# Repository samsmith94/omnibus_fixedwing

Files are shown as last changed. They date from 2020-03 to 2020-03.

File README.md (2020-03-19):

# Supplementary board for Omnibus F4 V3.

With this board, you can relocate your Omnibus Flight Controller to another model, since soldering is not required at all.

It is very convenient to use with the on-board
- GY-NEO8MV2 pin header
- 3-pin JST connector for FPV camera
- 3-pin JST connector for FPV transmitter
- 6-pin JST connector for Racerstar Shot30AESC
- 3-pin connector for WS2812B LED strip
- piezo buzzer.

Additionally there is an RFM95 LoRa modul + Atmega 328P + SMA connector for experimental LoRa-RC.

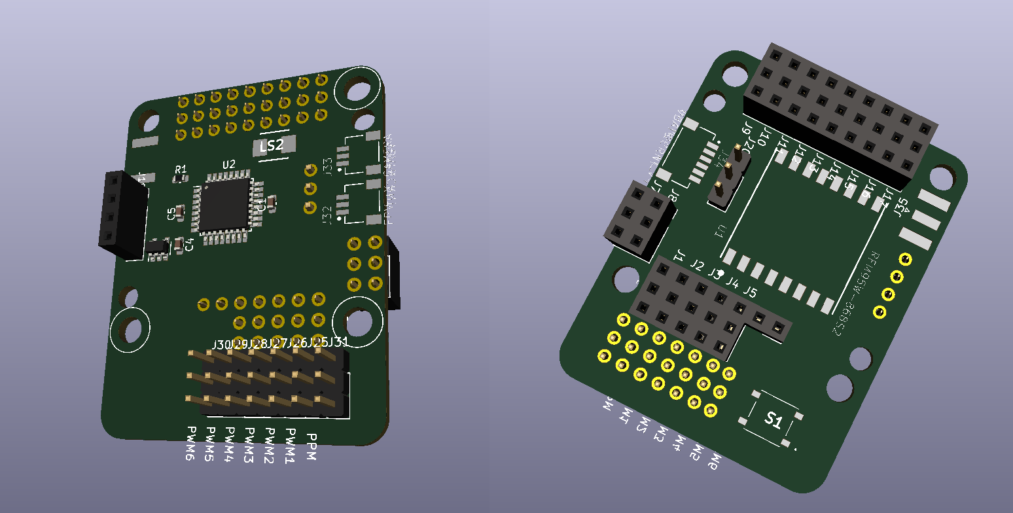
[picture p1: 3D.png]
3D model


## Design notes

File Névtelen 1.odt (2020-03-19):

1 mm pitch SMD female PCB aljzat + 10 cm wire

https://www.amazon.com/JST-SH-Female-Connector-Straight-Header/dp/B07KYHKSLN

Rendes boltból (farnell)

https://hu.farnell.com/w/c/connectors/wire-to-board-connectors?pitch-spacing=1mm&no-of-contacts=3contacts

konkrétan ez a legjobb

https://hu.farnell.com/jst-japan-solderless-terminals/sm03b-srss-tb-lf-sn/header-r-a-3way/dp/1679118

hozzá snapeda footprint&symbol

https://www.snapeda.com/parts/SM03B-SRSS-TB(LF)(SN)/JST/view-part/

omnibus dokumentáció

https://newtn.net/flori-schmid/2017/08/14/omnibus-f4-v3-documentation/

https://github.com/betaflight/betaflight/wiki/Board---OMNIBUSF4

https://www.youtube.com/watch?v=z3gCFm83cVw

lorarc

https://www.youtube.com/watch?v=bZgweGUDXOE

https://github.com/winiak/LoRaRC

atmega328 a lorahoz

https://www.hestore.hu/prod_10032542.html

betaflght fixed wing setup

https://github.com/betaflight/betaflight/wiki/Setup-for-a-Fixed-Wing-Aircraft

olcsó buzzer

https://hu.mouser.com/ProductDetail/TDK/PS1240P02BT?qs=sGAEpiMZZMs%252B6Ea5iKw4JnKB8rEmL0Rz

turnigy binb

https://www.youtube.com/watch?v=SnbP73vutww

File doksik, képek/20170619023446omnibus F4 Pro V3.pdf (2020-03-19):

Omnibus F4 Pro V3 Pinout

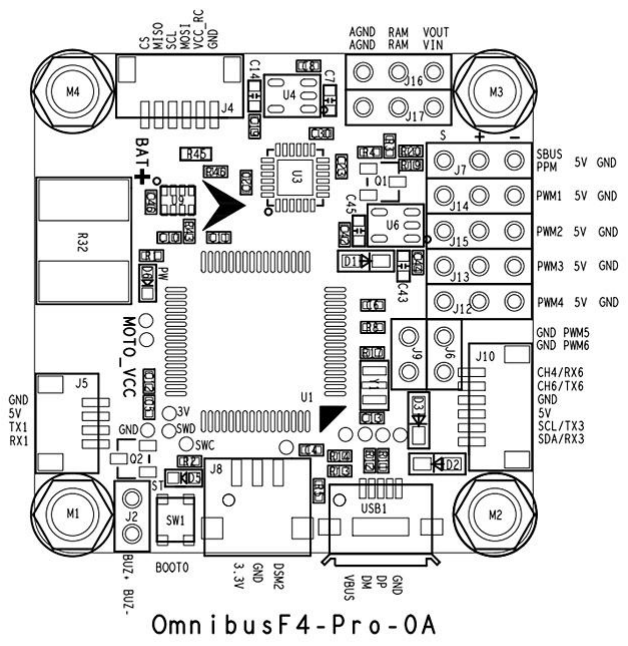
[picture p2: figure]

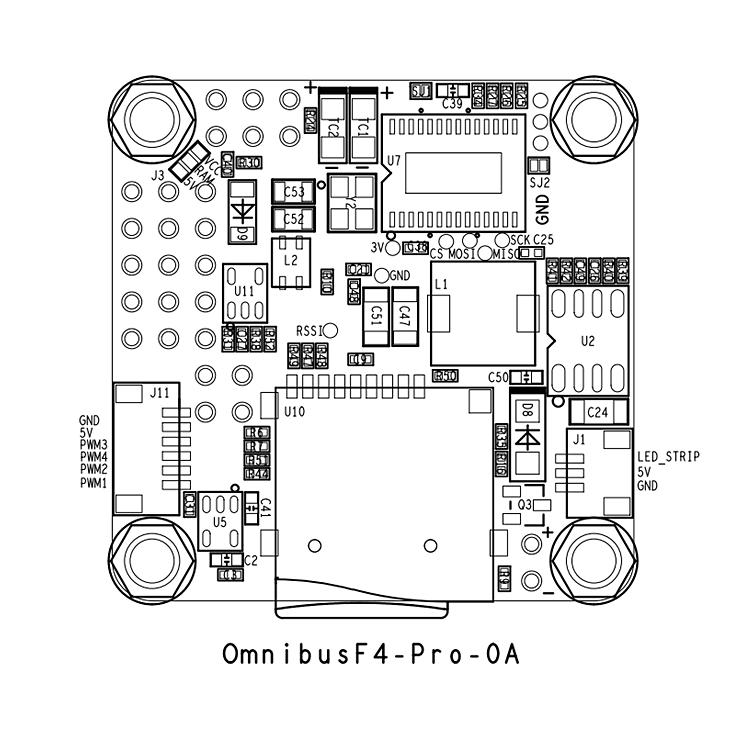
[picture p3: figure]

Wiring Diagram

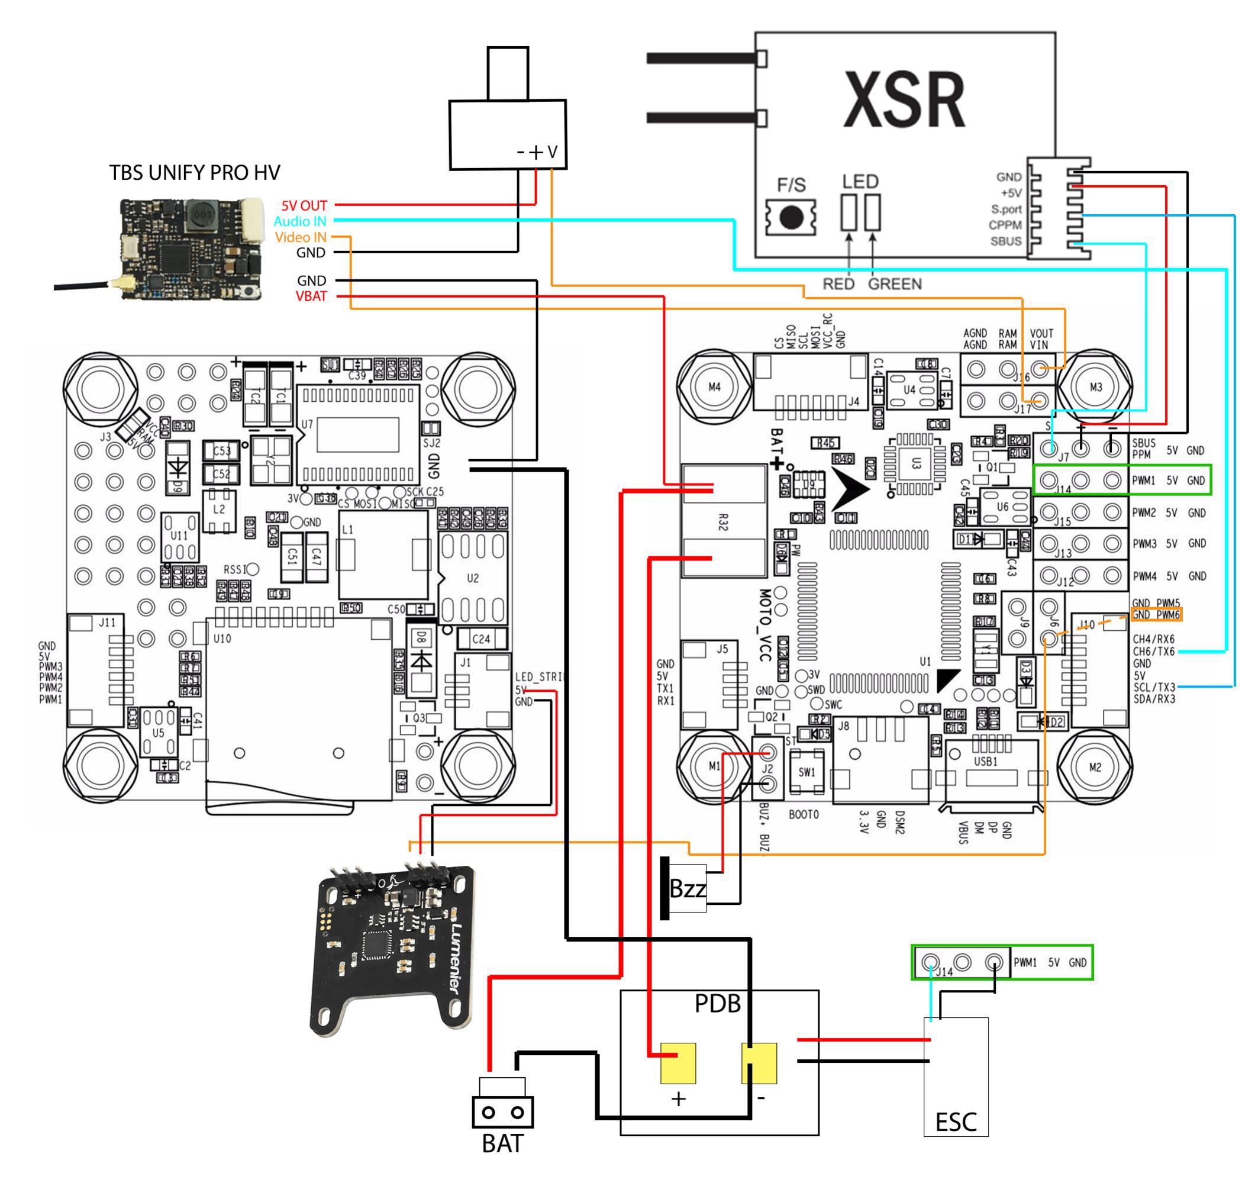
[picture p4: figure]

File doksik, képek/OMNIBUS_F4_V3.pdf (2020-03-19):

1 4 . A U G U S T 2 0 1 7 | V O N | F L O R I

# OMNIBUS F4 V3 – Documentation

Since there is no documentation at all on any of these F4 boards, here is my try:
– STM32F405 LQFP64 (168Mhz, 1M ash, 192kB SRAM)
– MPU6000 6DOF IMU
– BMP280 barometer
– MAX7456 OSD (or fake)
– 5V Switching regulator (MP2359)
– 6pin SM06B-SRSS connector to ESC (ts Racestar RS20A4V2) – DSM2 port for SPEKTRUM satellit
– USB CDC serial, DFU rmware update
– micro SD card slot for Blackbox logging

Latest rmware on Betaight github releases (V3.2.0) Congurator as Chrome App

Specication:
Power Supply MP2359 (1.4MHz switching regulator)
Input Voltage: max 24V (input capacitors may limit voltage to 4S) Output Current: max. 1.2A (1.8A current Limit)

3.3V LDO (100mA?)

Accessable pins

LABEL PIN TIMER DMA LQFP64
PIN

NOTE

RSSI | A0 | | | 14 | Not ADC capable
PWM5 | A1 | 5,2 | 1,4 | 15 | SoftSer 11 RX(/TX)
PWM4 | A2 2,3 | 1,1 | 16 | Motor 4
PWM3 | A3 2,4 | 1,6 | 17 | Motor 3
PWM6 | A8 1,1 | 2,3 | 41 | SoftSer 11 TX(/RX)
UART1 TX | A9 1,2 | 2,2 | 42
UART1 RX | A10 1,3 | ?,? | 43 | DSM2 SPEKSAT
PWM1 | B0 3,3 | 1,7 | 26 | Motor 1
PWM2 | B1 | 3,4 | 1,2 | 27 | Motor 2
Buzzer | B4 | | | 56
LED_STRIP B6 4,1 | 1,0 | 58 | WS2812 LED
PPM | B8 12,3 | n.a | 61 | PPM (if jumpered)
CH2 | B9 | | | 62 | ? wrong in BF github.
UART3 TX B10 2,3(!) | ?,? | 29 | Shared I²C resource
UART3 RX B11 2,4(!) | ?,? | 30 | Shared I²C resource
CRNT | C1 | — | 2,4 | 9 | external current sense ADC
VBAT | C2 — | 2,4 | 10 | internal VBat voltage
| | | | | divider ADC

LABEL PIN TIMER DMA LQFP64 PIN

NOTE

UART6 TX C6 8,1 | 2,2 | 37
UART6 RX C7 8,2 | 2,3 | 38 | SBUS (if jumpered)

Note: Serial ports in CAPITALs are Serial1; Serial3; Serial6, Serial11 (=SoftSer1); Serial12 (=SoftSer2)
In sourcecode and portforwarding use number-1: serial0; serial2; serial5…

Internal

LABEL | PORT TIMER DMA LQFP64
PIN

NOTE

USB_D+ | A12 | 45 | USB data plus
USB_D- | A11 | 44 | USB data minus
SWD | A13 | 46 | SWD_DIO
SWC | A14 | 49 | SWD_CLK
OSC_IN | H0 | 5
OSC_OUT | H1 | 6
SPI1_MISO | A6 | 22 | MPU600 SPI
SPI1_MOSI | A7 | 23
SPI1_CLK | A5 | 21
SPI1_CS_MPU A4 | 20
MPU_INT | C4 | 24

MPU6000
Interrupt output
SPI2_MISO | B14 | 35 | SD card SPI
SPI2_MOSI | B15 | 36

LABEL | PORT TIMER DMA LQFP64
PIN

NOTE

SPI2_CLK | B13 | 34
SPI2_CS_SD | B12 | 33
SD_DETECT | B7 | 59 | SD Card detect switch
SPI3_MISO | C11 | 52 | BARO & OSD SPI
SPI3_MOSI | C12 | 53
SPI3_CLK | C10 | 51
SPI3_CS_Baro B3 | 55
SPI3_CS_OSD A15 | 50
INVERTER | C8 | 39 | Logic Level inverter enable
LED1 | C5 | 57 | onboard LED (blue)
| B2 | 28 | GND
| C3 | 11 | resistor with NRST?
| C13 | 2 | unrouted
| C14 | 3 | unrouted
| C15 | 4 | unrouted

Where to buy:
ebay (DE)
ebay (CN)

The following is pretty much for my own conguration, but might be useful for you as well:

Set throotle check min:
set min_check = 1045

Setup SoftSer 11 for runcam control: resource Motor 5 none
resource Motor 6 none
resource serial_rx 11 A1
resource serial_tx 11 A8

Get Mag working on UART3/I²C2: resource Serial_TX 3 none
resource Serial_RX 3 none
resource i2c_scl 2 b10
resource i2c_sda 2 b11

Dont forget to:
save

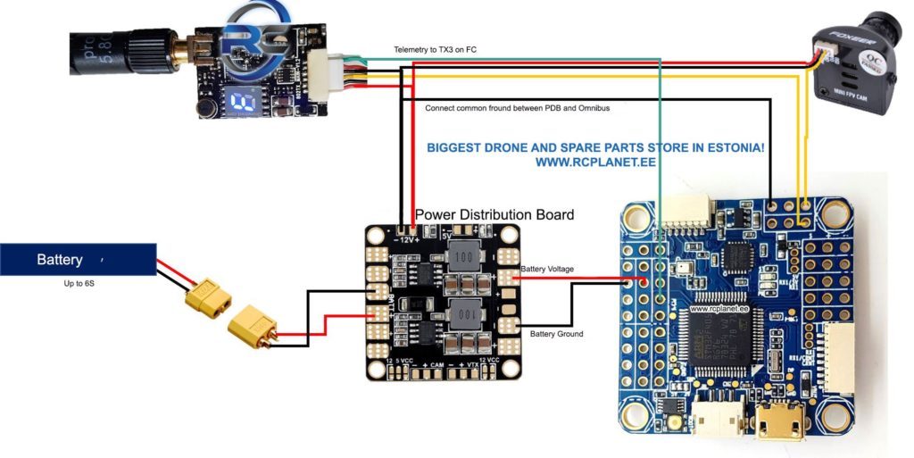
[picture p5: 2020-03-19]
doksik, képek/vbat és kamera.jpg

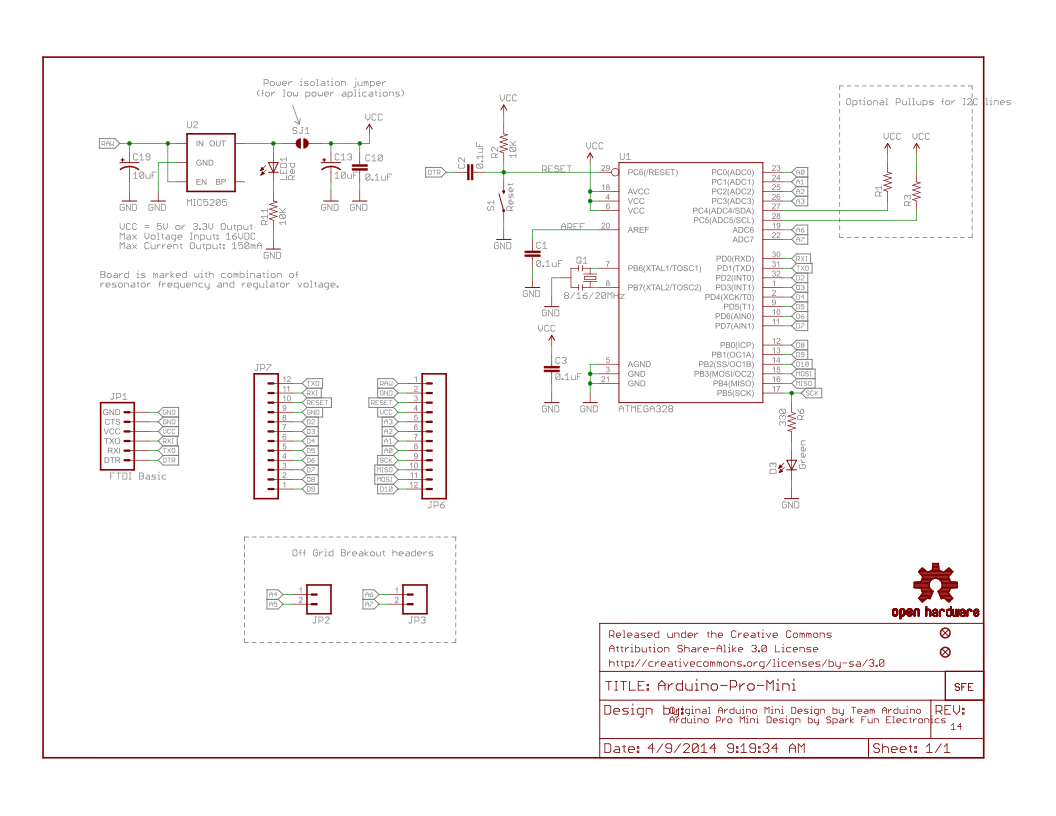
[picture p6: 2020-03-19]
doksik, képek/Arduino-Pro-Mini-v14.gif

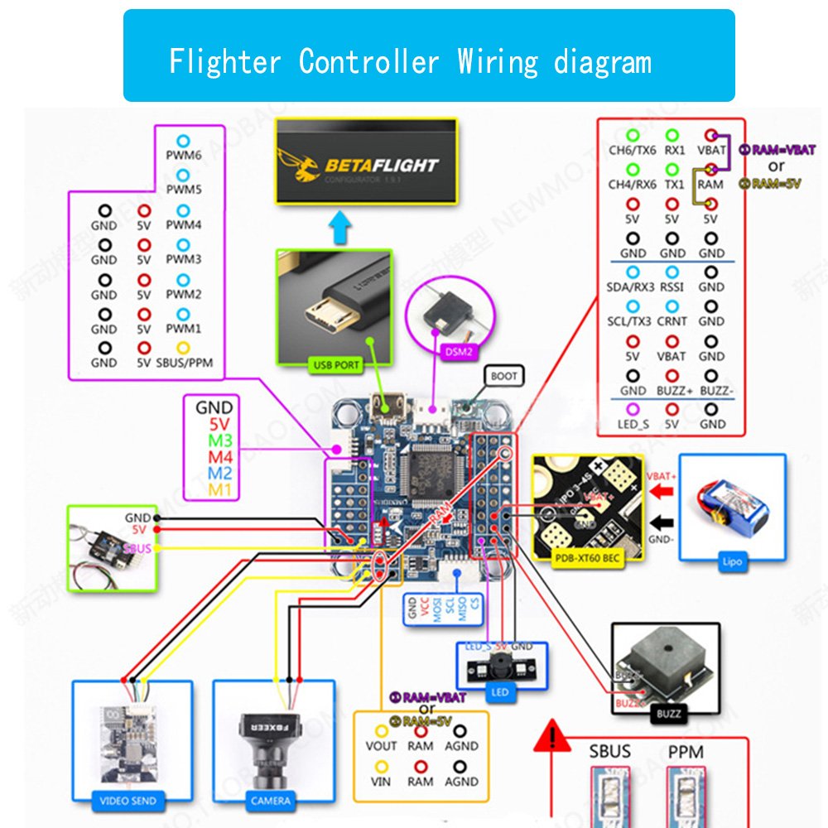
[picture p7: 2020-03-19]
doksik, képek/minden pin.jpg

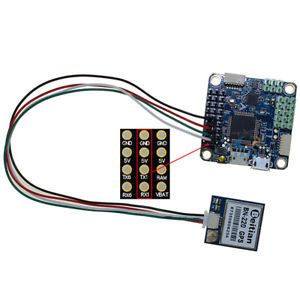
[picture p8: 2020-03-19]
doksik, képek/gps.jpg

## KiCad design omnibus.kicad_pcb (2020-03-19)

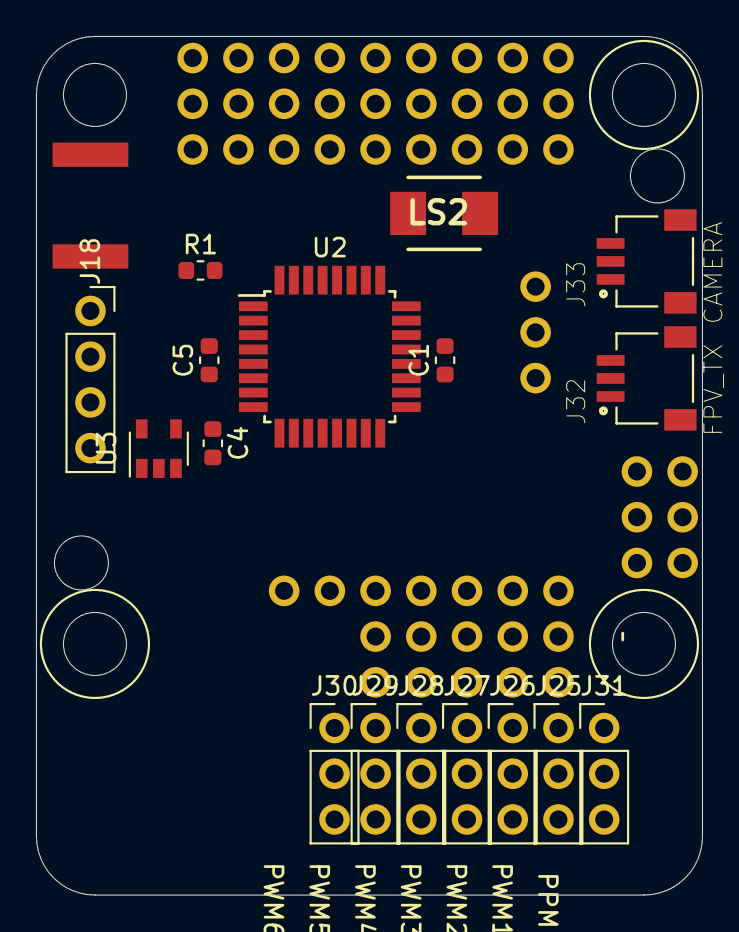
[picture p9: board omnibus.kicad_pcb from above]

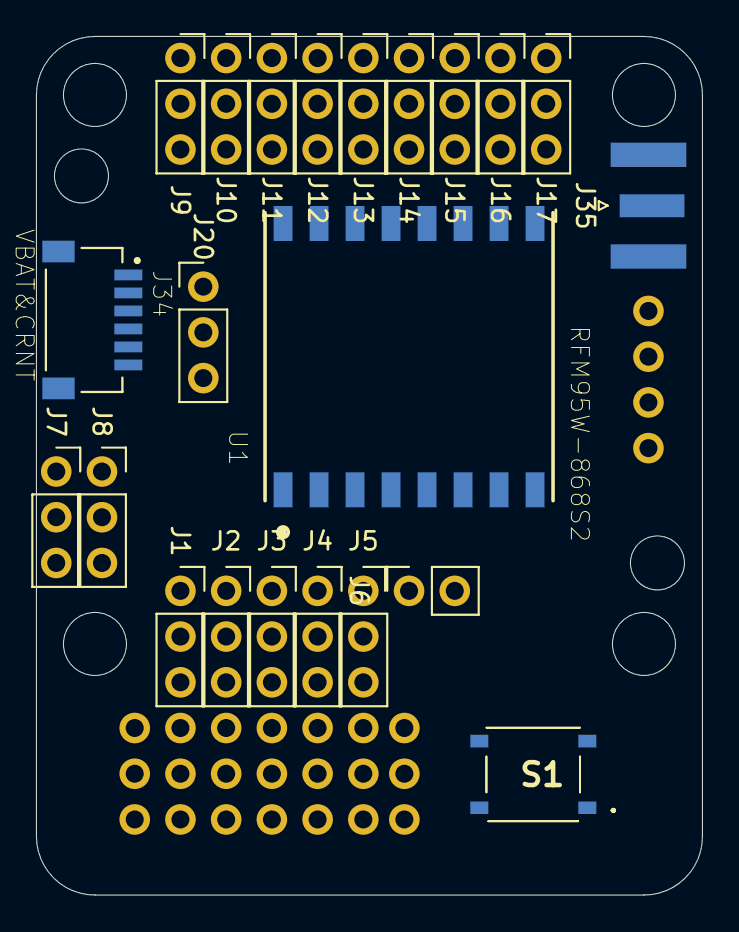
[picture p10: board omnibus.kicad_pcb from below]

Board: 2 copper layers, 37.0 x 47.7 mm, 39 parts (22 on the bottom side), 30 nets, no tracks yet.

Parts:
C1, C4, C5: 0,1uF; C_0603_1608Metric
J1: RC; PinSocket_1x03_P2.54mm_Vertical
J2: PWM1; PinSocket_1x03_P2.54mm_Vertical
J3: PWM2; PinSocket_1x03_P2.54mm_Vertical
J4: PWM3; PinSocket_1x03_P2.54mm_Vertical
J5: PWM4; PinSocket_1x03_P2.54mm_Vertical
J6: PWM5&6; PinSocket_1x02_P2.54mm_Vertical
J7: VIN; PinSocket_1x03_P2.54mm_Vertical
J8: VOUT; PinSocket_1x03_P2.54mm_Vertical
J9: LED; PinSocket_1x03_P2.54mm_Vertical
J10: BUZ; PinSocket_1x03_P2.54mm_Vertical
J11: VBAT; PinSocket_1x03_P2.54mm_Vertical
J12: CRNT&SCL/TX3; PinSocket_1x03_P2.54mm_Vertical
J13: RSSI&SDA/RX3; PinSocket_1x03_P2.54mm_Vertical
J14: GND; PinSocket_1x03_P2.54mm_Vertical
J15: 5V; PinSocket_1x03_P2.54mm_Vertical
J16: RAM&TX1&TX6; PinSocket_1x03_P2.54mm_Vertical
J17: RX1&RX6; PinSocket_1x03_P2.54mm_Vertical
J18: GPS; PinSocket_1x04_P2.54mm_Vertical
J20: LED_STRIP; PinHeader_1x03_P2.54mm_Vertical
J25, J26, J27, J28, J29, J30, J31: Conn_01x03_Male; PinHeader_1x03_P2.54mm_Vertical
J32: FPV_TX; JST_SM03B-SRSS-TB(LF)(SN)
J33: CAMERA; JST_SM03B-SRSS-TB(LF)(SN)
J34: VBAT&CRNT; JST_SM06B-SRSS-TB(LF)(SN)
J35: Conn_Coaxial; SMA_Samtec_SMA-J-P-H-ST-EM1_EdgeMount
LS2: CMT-4023S-SMT-TR; CMT-4023S
R1: 10k; R_0603_1608Metric
S1: PTS526_SK08_SMTR2_LFS; PTS526SKG15SMTR2LFS
U1: RFM95W-868S2; XCVR_RFM95W-868S2
U2: ATmega328P-AU; TQFP-32_7x7mm_P0.8mm
U3: MIC5205-3.3YM5; SOT-23-5

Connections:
+3V3: C4.1, C5.1, R1.1, U1.13, U2.4, U2.6, U2.18, U3.5
+5V: J1.2, J2.2, J3.2, J4.2, J5.2, J9.2, J11.3, J15.1, J15.2, J15.3, J18.1, J20.1
CRNT: J12.2, J34.1
DO: J9.3, J20.2
GND: C1.2, C4.2, C5.2, J1.3, J2.3, J3.3, J4.3, J5.3, J9.1, J10.3, J11.1, J12.1, J13.1, J14.1, J14.2, J14.3, J18.4, J20.3, J25.3, J26.3, J27.3, J28.3, J29.3, J30.3, J32.2, J33.2, J34.5, J34.6, J35.2, S1.4, U1.1, U1.8, U1.10, U2.3, U2.5, U2.21, U3.2
GNDA: J7.1, J8.1
MISO: U1.2, U2.16
MOSI: U1.3, U2.15
unnamed: C1.1, U2.20
unnamed: U3.1, U3.3
unnamed: J32.S1, J32.S2
unnamed: J33.S1, J33.S2
unnamed: J34.S1, J34.S2
unnamed: J35.1, U1.9
PPM_FROM_RC: J1.1, J31.1
PWM1: J2.1, J25.1
PWM2: J3.1, J26.1
PWM3: J4.1, J27.1
PWM4: J5.1, J28.1
PWM5: J6.1, J29.1
PWM6: J6.2, J30.1
RAM: J7.2, J8.2, J16.1
RESET: R1.2, S1.2, U1.6, U2.29
RX: J16.2, J18.2
RX1: J17.2, J18.3
SCK: U1.4, U2.17
SS: U1.5, U2.14
VBAT: J11.2, J17.1, J34.2
VIN: J7.3, J33.1
VOUT: J8.3, J32.1

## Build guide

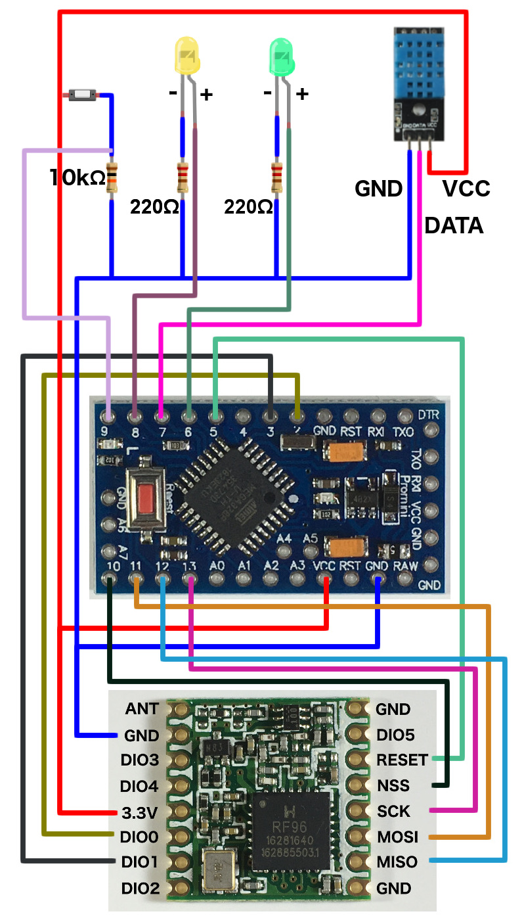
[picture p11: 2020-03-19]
doksik, képek/lora arduino wiring.jpg
